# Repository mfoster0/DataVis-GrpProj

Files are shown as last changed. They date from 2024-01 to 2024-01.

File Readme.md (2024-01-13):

# Sea Ice Extent Gauge #
> CASA0019: Sensor Data Visualisation.

> Group 6 - Ice Ice Baby (Mark Foster, Satria Mitra Utama, Qingyao Tang).

<p align="center" width="100%">
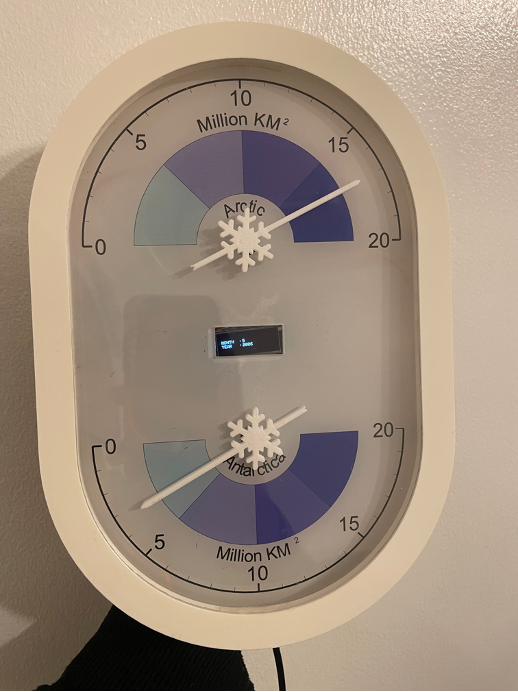
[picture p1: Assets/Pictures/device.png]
     
</p>

## Overview
This guide provides step-by-step instructions for building the Sea Ice Extent Gauge, a device designed to visualize changes in polar sea ice. This project, part of the CASA0019 course at University College London, aims to raise awareness about sea ice's importance and the impact of climate change.

## Table of Content
<details>
<summary>(click to expand)</summary>

1. Introduction
2. Components Required
3. Assembly Instructions
4. Software Setup
5. Using the Device
6. Additional Resources
7. References
8. Contributors

</details>

## 1. Introduction
The Sea Ice Extent Gauge visualizes real-time changes in Arctic and Antarctic sea ice coverage. It combines a physical device with an interactive digital twin, highlighting the urgency of environmental protection.

## 2. Components Required
- Raspberry Pico W microcontroller
- MG90S servos (2)
- 0.91-inch OLED display
- Metal Push Button LED
- Various electronic components (resistors, wires, etc.)

## 3. Assembly Instructions
### 3.1 Building the Hardware

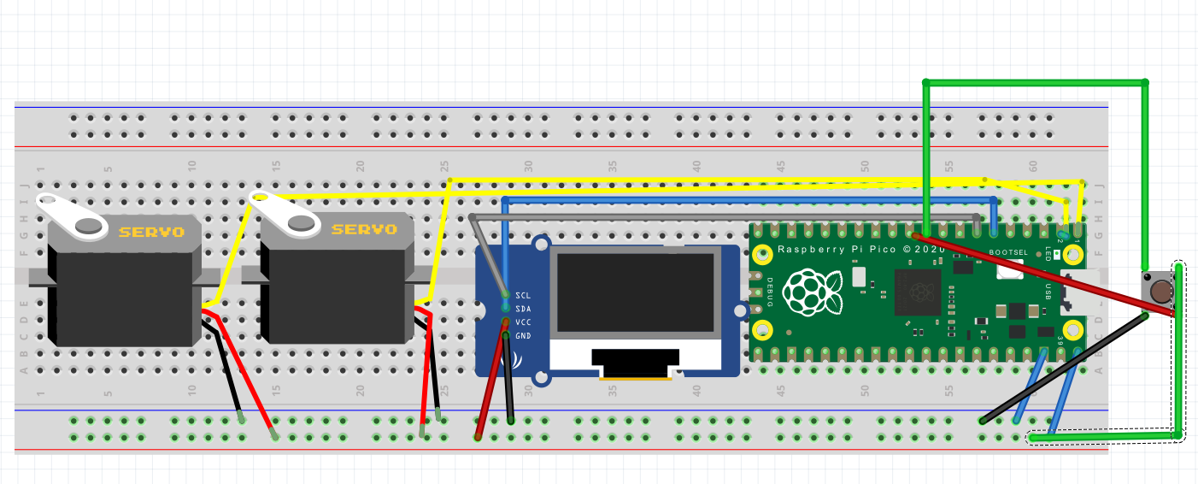
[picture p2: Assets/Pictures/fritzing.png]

Assemble the physical gauge using the Raspberry Pico W as the control center, connect the servos, OLED display, and LED push button according to the pin configuration provided.

|No|Components	    |Pin	|Raspberry Pico Pin|
---|----------------|:-----:|:----------------:|
|1 |Servo MG90S (1)	|VCC	|VBUS  | 
|  |	            |GND	|GND   |
|  |	            |Data	|GP0   |
|2 |Servo MG90S (2)	|VCC	|VBUS  |
|  |		        |GND	|GND   |
|  |	            |Data	|GP1   |
|3 |Oled Display 0.91 Inch|	VCC|	VBUS|
|	|	|GND|	GND|
|	|	|SDA	|GP4|
|	|	|SCL	|GP5|
|4|	LED Push Button|	VCC (+)	|GP8
|	|	|GND (-)	|GND
|	|	|SW0	|VBUS|
|	|	|SW1	|GP7|

### 3.2 Crafting the Physical Display
Create two semicircular charts to represent sea ice cover in the Arctic and Antarctic. Use shades of blue to indicate changes in ice coverage.

## 4. Software Setup
### 4.1 Programming the Raspberry Pico
#### 4.1.1 Install libraries
Set up the Raspberry Pico using Arduino IDE and run script `dial_gauge.ino`that collects data from MQTT Broker. 
Install necessary libraries like :
- [ESP8266 wifi](https://github.com/esp8266/Arduino/tree/master/libraries/ESP8266WiFi)
- [Pubsub client](https://www.arduino.cc/reference/en/libraries/pubsubclient/)
- [Adafruit Oled SSD1306](https://www.arduino.cc/reference/en/libraries/adafruit-ssd1306/)
- [Adafruit GFX Library](https://www.arduino.cc/reference/en/libraries/adafruit-gfx-library/)

#### 4.1.2 Config mqtt brokers & wifi
Create file named `arduino_secrets.h` within the same folder of the scripts and add your mqtt broker details 
```
//MQTT Broker & password
const char* mqttuser = "<username>";
const char* mqttpass = "<password>";
const char* mqtt_server = "<host>";
```
Don't forget to chane your wifi credentials on the scripts
```
const char* ssid = "<wifi>";
const char* password = "<password>";
```

### 4.2 Unity Augmented Reality Integration
Develop an AR version using Unity to mimic the physical device. Include additional functionalities like displaying videos and extra data on sea ice changes.

Scan this qrcode to install the AR application for Android

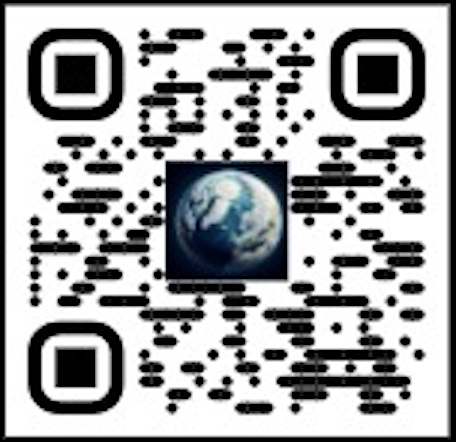
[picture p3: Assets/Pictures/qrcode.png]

## 5. Using the Device
### 5.1 Interacting with the Gauge
The device uses servos to indicate sea ice extent and an OLED display to show dates. Press the LED button to toggle between historical and current data.

### 5.2 Exploring the Digital Twin
Use the Unity AR interface to access more detailed information and visualizations about sea ice changes.

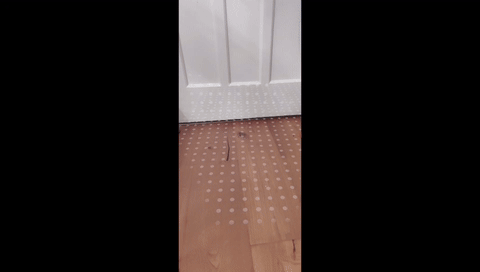
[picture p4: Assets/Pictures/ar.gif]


## 6. Additional Resources
- [GitHub Repository](https://github.com/mfoster0/DataVis-GrpProj)
- Assembly diagrams and schematics

## 7. Contributors
- Mark Foster
- Satria Mitra Utama
- Qingyao Tang

---

*This README was created for the Sea Ice Extent Gauge project, part of the CASA0019 course at University College London by Group 6, Ice Ice Baby.*

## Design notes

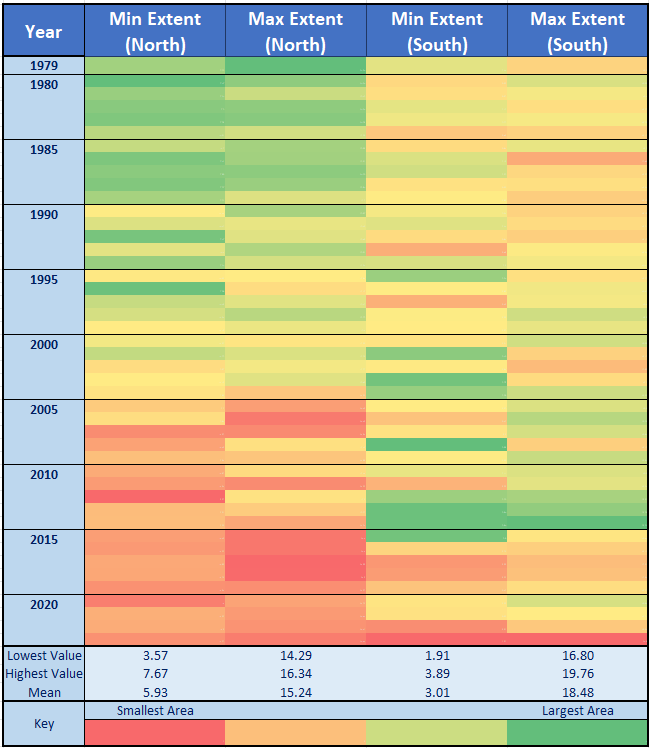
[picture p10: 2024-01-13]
Unity/Assets/Images/HeatMap.png

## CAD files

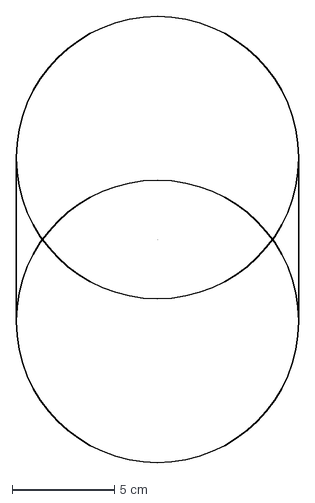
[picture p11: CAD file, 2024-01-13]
Assets/Acrylic/acrylic v1.dxf
13.8 x 21.8 cm

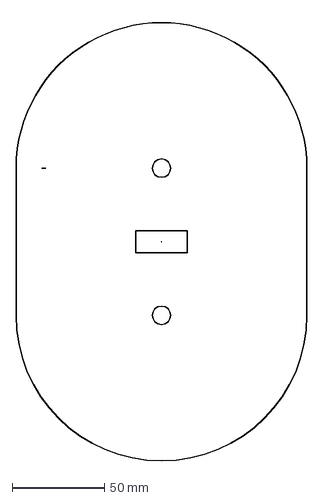
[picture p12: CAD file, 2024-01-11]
Assets/Face hole/face_platehole_1.dxf
158.0 x 241.5 mm

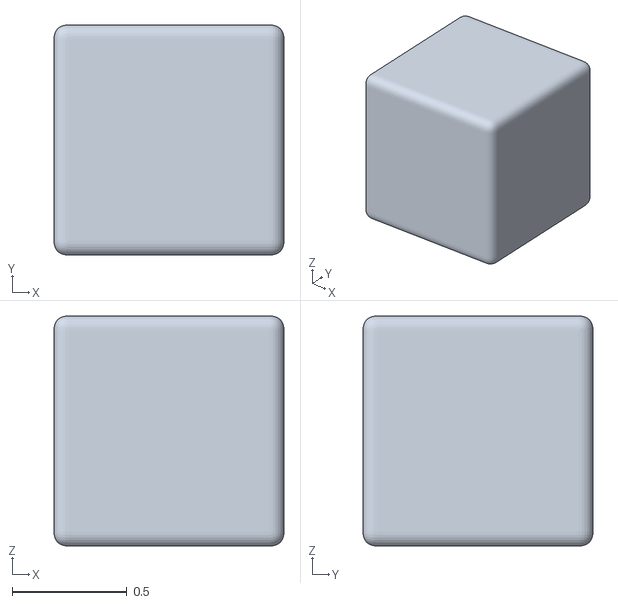
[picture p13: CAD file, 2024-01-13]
Unity/Assets/Plugins/CW/LeanCommon/Examples/Meshes/RoundedCube.obj
1.00 x 1.00 x 1.00

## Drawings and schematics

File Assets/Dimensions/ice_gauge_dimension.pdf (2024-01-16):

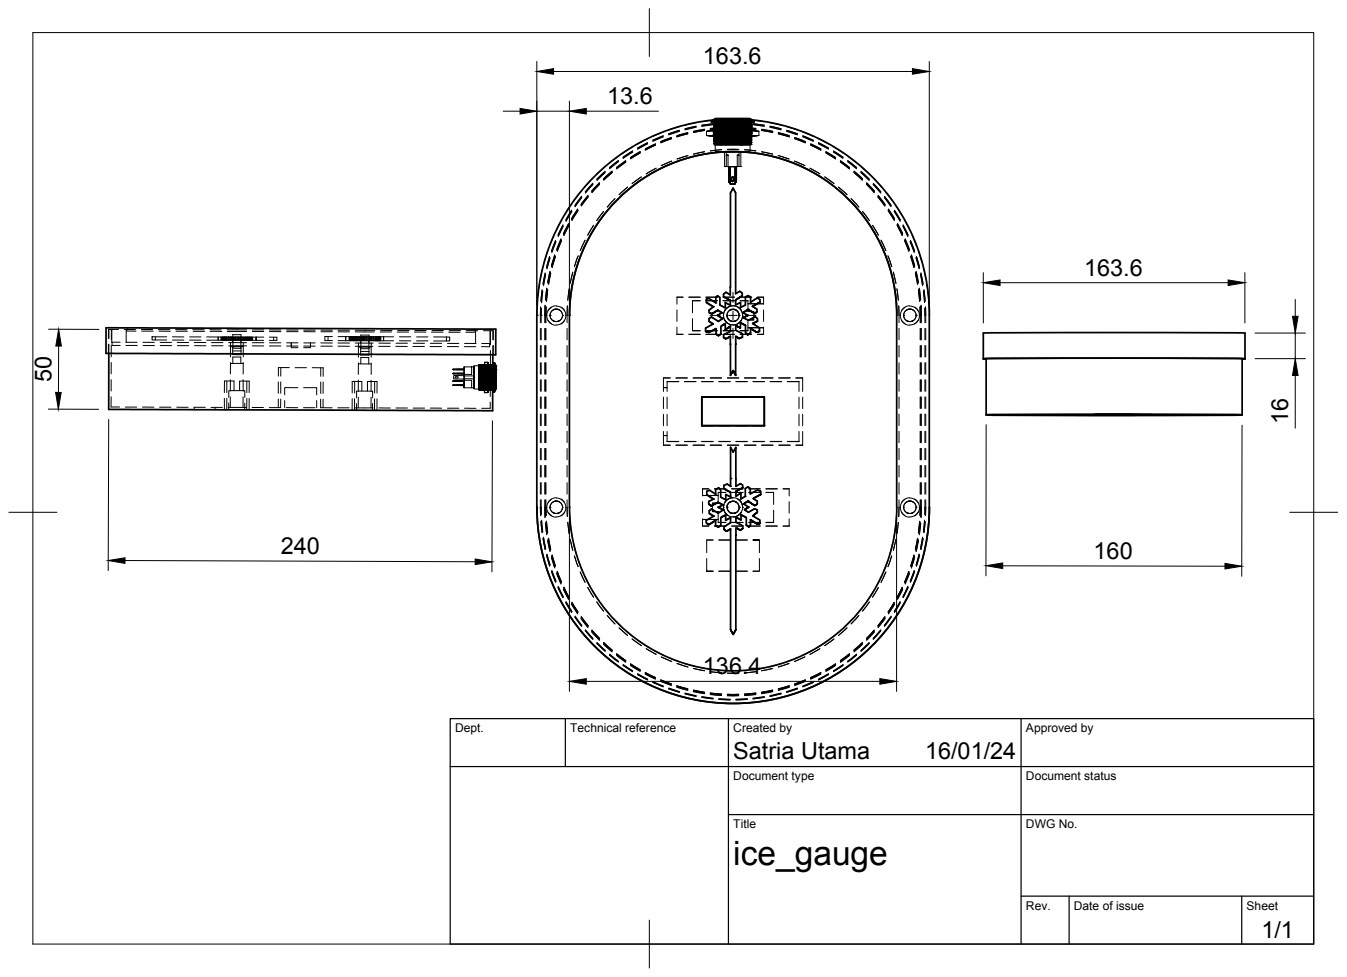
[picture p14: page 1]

Dept. | Technical reference | Created by Satria Utama 16/01/24 | Approved by

Document type | Document status

Title ice_gauge | DWG No.

Rev. | Date of issue | Sheet 1/1

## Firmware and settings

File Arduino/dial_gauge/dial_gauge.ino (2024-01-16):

#include <ESP8266WiFi.h>
#include <PubSubClient.h>
#include <Servo.h>
#include <Arduino.h>
#include <Adafruit_SSD1306.h>
#include <Adafruit_GFX.h>
#include <SPI.h>
#include <Wire.h>

#include "arduino_secrets.h"

char receivedMessage[5]; 
char monthReceived[5]; // Store the received month
char yearReceived[5];  // Store the received year
char stateReceived[5];  // Store the received year

// // Wifi at home
// const char* ssid = "VM9486848";
// const char* password = "5rfzxumhPkya8nxA";

// CE Lab wifi
const char* ssid = "CE-Hub-Student";
const char* password = "casa-ce-gagarin-public-service";

// // Wifi at Gintare
// const char* ssid = "4B87 Hyperoptic 1Gb Fibre 2.4Ghz";
// const char* password = "47EAgzx59EFA";

// Define topic to subscribe
const char* north = "student/CASA0019/G6/data/north";

const char* south = "student/CASA0019/G6/data/south";
const char* month = "student/CASA0019/G6/data/month";
const char* year = "student/CASA0019/G6/data/year";
const char* currentyear = "student/CASA0019/G6/data/currentyear";
const char* currentmonth = "student/CASA0019/G6/data/currentmonth";
const char* northDailyExtent = "student/CASA0019/G6/data/northDailyExtent";
const char* southDailyExtent = "student/CASA0019/G6/data/southDailyExtent";

const char* stateTopic = "student/CASA0019/G6/data/displayDaily";

int currentState = 0; // Variable to hold the current state

WiFiClient espClient;
PubSubClient client(espClient);

// Define servo objects
Servo servo1;
Servo servo2;

//Define LED Panel
Adafruit_SSD1306 display(128, 32);

//Define button pin
const int ledbutton = 8; // ESP8266's built-in LED pin
const int buttonPin = 7; // Define the pin for the button
int buttonState = 0; // Initialize variable to hold the button state
int lastButtonState = 0; // Initialize variable to hold the previous button state
int state = 0;

int ledState = 0; // Initialize variable to hold the LED state
//const int ledPin = LED_BUILTIN; // Define the pin for the LED

unsigned long lastDebounceTime = 0;  // the last time the output pin was toggled
unsigned long debounceDelay = 50;   

void setup() {
  Serial.begin(115200);
  delay(500);

  servo1.attach(2, 500, 2400); // Replace D1 with the pin number for servo 1
  servo2.attach(3, 500, 2400); // Replace D2 with the pin number for servo 2
  //servo1.write(3); 
  //servo2.write(3); 

  // // Servo Sweep - Useful for Calibration - Edit for own Servo/Dial Range
  // servo1.setEasingType(EASE_LINEAR);
  // servo2.setEasingType(EASE_LINEAR);

  // servo1.setSpeed(15);
  // servo2.setSpeed(15);

  Serial.print("Moving to 0");
  servo1.write(0);
  servo2.write(0);

  
  delay (1000);
  Serial.print("Moving to 180");
  servo1.write(180);
  servo2.write(180);

  delay (1000);
  
  Serial.print("Moving to 0");
  servo1.write(0);
  servo2.write(0);

  Serial.print("Pausing for 1 seconds");
  delay (2000);

  startWifi();

  client.setServer(mqtt_server, 1884);
  client.setCallback(callback);
  subscribeToTopic(north);
  subscribeToTopic(south);
  subscribeToTopic(month);
  subscribeToTopic(year);
  subscribeToTopic(northDailyExtent);
  subscribeToTopic(currentmonth);
  subscribeToTopic(currentyear);
  subscribeToTopic(southDailyExtent);

  subscribeToTopic(stateTopic);

  Serial.println("IP address: ");
  Serial.println(WiFi.localIP());




  display.begin(SSD1306_SWITCHCAPVCC, 0x3C);  // Address 0x3D for 128x32
  pinMode(buttonPin, INPUT); // Set the button pin as an input
  //pinMode(ledPin, OUTPUT); // Set LED pin as an output
  pinMode(ledbutton, OUTPUT); // Set LED pin as an output
  display.clearDisplay();

}

void loop() {
  client.loop();

  // Read the current state of the button
  int reading = digitalRead(buttonPin);

  // Check if the button state has changed
  if (reading != lastButtonState) {
    // Reset the debouncing timer
    lastDebounceTime = millis();
  }

  // If the button state has been different for longer than the debounce delay,
  // we assume that the button state has changed:
  if ((millis() - lastDebounceTime) > debounceDelay) {
    // If the button state has changed:
    if (reading != buttonState) {
      buttonState = reading;

      // Only toggle the state if the new button state is HIGH
      if (buttonState == HIGH) {
        Serial.println("Button Pressed");
        state = 1 - state;
        Serial.print("Current State: ");
        Serial.println(state);
        sendStateViaMQTT();
      }
    }
  }

  // Save the reading for the next loop
  lastButtonState = reading;
}

void sendStateViaMQTT() {
  char msg[10];
  snprintf(msg, 10, "%d", state);
  client.publish(stateTopic, msg);
}

// void checkState() {
//   if (currentState == 1) {
//     performTaskB(); // Perform Task B when the state is 1
//   } else {
//     performTaskA(); // Perform Task A when the state is 0
//   }
// }

void displayMessage(const char* month, const char* year) {
  display.clearDisplay();
  display.setTextColor(WHITE);
  // display.setTextSize(1);
  // display.setCursor(0, 0); // Set the cursor position
  // display.print(" Arctic: "); // Display the received message on the OLED
  // display.setCursor(62, 0); // Set the cursor position
  // display.print("Antarctica:"); // Display the received message on the OLED
  // display.setTextSize(2);
  // display.setCursor(0, 10); // Set the cursor position
  // display.print("15"); // Display the received message on the OLED
  // display.setCursor(27, 10); // Set the cursor position
  // display.print("KM"); // Display the received message on the OLED
  // display.setCursor(48, 10); // Set the cursor position
  // display.write(252);
  // display.setCursor(67, 10); // Set the cursor position
  // display.print("20"); // Display the received message on the OLED
  // display.setCursor(94, 10); // Set the cursor position
  // display.print("KM"); // Display the received message on the OLED
  // display.setCursor(115, 10); // Set the cursor position
  // display.write(252);

  display.setTextSize(1);
  display.setCursor(0, 10); // Set the cursor position
  display.print("MONTH  :"); // Display the received message on the OLED
  display.setCursor(50, 10); // Set the cursor position
  display.print(month); // Display the received message on the OLED
  display.setCursor(0, 20); // Set the cursor position
  display.print("YEAR   :"); // Display the received message on the OLED
  display.setCursor(50, 20); // Set the cursor position
  display.print(year); // Display the received message on the OLED

  display.display(); 
}


void reconnect() {
  while (!client.connected()) {
    Serial.print("Attempting MQTT connection...");
    String clientId = "ESP8266Client-";
    clientId += String(random(0xffff), HEX);

    if (client.connect(clientId.c_str(), mqttuser, mqttpass)) {
      Serial.println("connected");
      client.subscribe("student/CASA0019/G6/data/inTopic");
    } else {
      Serial.print("failed, rc=");
      Serial.print(client.state());
      Serial.println(" try again in 5 seconds");
      delay(5000);
    }
  }
}

void subscribeToTopic(const char* mqttTopic) {
  if (!client.connected()) {
    reconnect();
  }

  if (client.subscribe(mqttTopic)) {
    //Serial.print("Subscribed to topic: ");
    //Serial.println(mqttTopic);
  } else {
    //Serial.print("Failed to subscribe to topic: ");
    //Serial.println(mqttTopic);
  }
}

void startWifi() {
  Serial.println();
  Serial.print("Connecting to ");
  Serial.println(ssid);
  WiFi.begin(ssid, password);
  while (WiFi.status() != WL_CONNECTED) {
    delay(500);
    Serial.print(".");
  }
  Serial.println("");
  Serial.println("WiFi connected");
  Serial.print("IP address: ");
  Serial.println(WiFi.localIP());
}

void moveServo1(Servo& servo1, int value) {
  int invertedValue = 20 - value; // Invert the value from 0-20 to 20-0
  int angle = map(invertedValue, 0, 20, 0, 180);
  servo1.write(angle); // Move the servo to the mapped angle
   // Calculate the difference in angle
  //int angleDifference = abs(servo1.read() - angle);

  //if (angleDifference < 10) {
  //servo1.setSpeed(5); // Slower for small changes
  //servo1.setEasingType(EASE_LINEAR); // Linear easing for smoother small movements
  //} else {
  //servo1.setSpeed(10); // Faster for larger changes
  //servo1.setEasingType(EASE_CUBIC_IN_OUT); // Cubic easing for larger movements
  // }
  //   // Move servo to the new position
  // servo1.easeTo(angle);
  delay(10); // Allow transit time
}

void moveServo2(Servo& servo2, int value) {
  int angle = map(value, 0, 20, 0, 180); 
  servo2.write(angle); // Move the servo to the mapped angle
   // Calculate the difference in angle
  // int angleDifference = abs(servo2.read() - angle);

  // if (angleDifference < 10) {
  // //servo2.setSpeed(5); // Slower for small changes
  // //servo2.setEasingType(EASE_LINEAR); // Linear easing for smoother small movements
  // } else {
  // //servo2.setSpeed(10); // Faster for larger changes
  // //servo2.setEasingType(EASE_CUBIC_IN_OUT); // Cubic easing for larger movements
  // }
  //   // Move servo to the new position
  // servo2.easeTo(angle);
  delay(10); // Allow transit time
}

void callback(char* topic, byte* payload, unsigned int length) {
  Serial.print("Message arrived ");
  Serial.println(topic);
  
 // Ensure the payload is null-terminated
  char payloadStr[length + 1]; // Create a buffer with an extra space for the null terminator
  memcpy(payloadStr, payload, length); // Copy the payload to the buffer
  payloadStr[length] = '\0'; // Null-terminate the string

  // Convert the null-terminated payload to an integer
  int value = atoi(payloadStr);
  Serial.print("Received Value: ");
  Serial.println(value);

  if (strcmp(topic, stateTopic) == 0) {
    currentState = value; // Set the current state based on the received value
    Serial.print("Current State: ");
    Serial.println(currentState);

    // Control LED button based on currentState
    if (currentState != 0) {
      digitalWrite(ledbutton, HIGH); // Turn on LED button when currentState is 1
    } else {
      digitalWrite(ledbutton, LOW); // Turn off LED button when currentState is 0
    }
  } else {
    // Handle other topics without impacting LED button control
    if (currentState == 0) {
      if (strcmp(topic, north) == 0) {
        moveServo1(servo1, value); // Control servo 1 based on the received value from 'north'
      } else if (strcmp(topic, south) == 0) {
        moveServo2(servo2, value); // Control servo 2 based on the received value from 'south'
      } else if (strcmp(topic, month) == 0) {
        snprintf(monthReceived, sizeof(monthReceived), "%.*s", length, (char*)payload);
        displayMessage(monthReceived, yearReceived); // Display received month on OLED
      } else if (strcmp(topic, year) == 0) {
        snprintf(yearReceived, sizeof(yearReceived), "%.*s", length, (char*)payload);
        displayMessage(monthReceived, yearReceived); // Display received year on OLED
      }
    } else if (currentState == 1) {
      if (strcmp(topic, northDailyExtent) == 0) {
        moveServo1(servo1, value); // Control servo 1 based on the received value from 'northDailyExtent'
      } else if (strcmp(topic, southDailyExtent) == 0) {
        moveServo2(servo2, value); // Control servo 2 based on the received value from 'southDailyExtent'
      } else if (strcmp(topic, currentmonth) == 0) {
        snprintf(monthReceived, sizeof(monthReceived), "%.*s", length, (char*)payload);
        displayMessage(monthReceived, yearReceived); // Display received current month on OLED
      } else if (strcmp(topic, currentyear) == 0) {
        snprintf(yearReceived, sizeof(yearReceived), "%.*s", length, (char*)payload);
        displayMessage(monthReceived, yearReceived); // Display received current year on OLED
      }
    }
  }
  //value = 0;
}

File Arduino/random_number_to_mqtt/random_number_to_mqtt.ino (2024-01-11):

#include <ESP8266WiFi.h>
#include <PubSubClient.h>
#include <ArduinoJson.h>

//wifi CE lab
const char* ssid = "CE-Hub-Student";
const char* password = "casa-ce-gagarin-public-service";

//wifi home
// const char* ssid = "VM9486848";
// const char* password = "5rfzxumhPkya8nxA";

const char* mqtt_server = "mqtt.cetools.org";
const int mqtt_port = 1884;
const char* mqtt_user = "student";
const char* mqtt_password = "ce2021-mqtt-forget-whale";

WiFiClient espClient;
PubSubClient client(espClient);

void setup_wifi() {
  delay(10);
  Serial.println();
  Serial.print("Connecting to ");
  Serial.println(ssid);

  WiFi.begin(ssid, password);

  while (WiFi.status() != WL_CONNECTED) {
    delay(500);
    Serial.print(".");
  }

  Serial.println("");
  Serial.println("WiFi connected");
  Serial.println("IP address: ");
  Serial.println(WiFi.localIP());
}

void reconnect() {
  while (!client.connected()) {
    Serial.print("Attempting MQTT connection...");
    if (client.connect("ESP8266Client", mqtt_user, mqtt_password)) {
      Serial.println("connected");
    } else {
      Serial.print("failed, rc=");
      Serial.print(client.state());
      Serial.println(" try again in 5 seconds");
      delay(5000);
    }
  }
}

void setup() {
  Serial.begin(115200);
  setup_wifi();
  client.setServer(mqtt_server, mqtt_port);
}

void loop() {
  if (!client.connected()) {
    reconnect();
  }
  client.loop();

  int randomNumber1 = random(0, 181);
  int randomNumber2 = random(0, 181);
  const char* curmonth = "December";
  int curyear = 2023;


  // Publish JSON messages to separate topics
  char jsonString1[10];
  char jsonString2[10];
  char jsonString3[10];
  char jsonString4[10];
    char jsonString5[10];



  snprintf(jsonString1, sizeof(jsonString1), "%d", randomNumber1);
  snprintf(jsonString2, sizeof(jsonString2), "%d", randomNumber2);
  snprintf(jsonString3, sizeof(jsonString3), "%d", 15);
  snprintf(jsonString4, sizeof(jsonString4), "%s", curmonth);
  snprintf(jsonString5, sizeof(jsonString4), "%d", curyear);



  client.publish("student/CASA0016/ucfnmut/random1", jsonString1);
  client.publish("student/CASA0016/ucfnmut/random2", jsonString2);
  client.publish("student/CASA0016/ucfnmut/curData", jsonString3);
  client.publish("student/CASA0016/ucfnmut/curMonth", jsonString4);
  client.publish("student/CASA0016/ucfnmut/curyear", jsonString5);



  Serial.println(jsonString1);
  Serial.println(jsonString2);
  Serial.println(jsonString3);
  Serial.println(jsonString4);
  Serial.println(jsonString5);




  delay(10000);
}

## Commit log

2023-11-29 adding python data manipulation script
    [MonthlyData.csv]
2023-12-05 Upload the code for arduino
2024-01-11 update github
    [MonthlyData.csv, scale_fix v2.dxf, scale_platehole.dxf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]
2024-01-11 update assets folder
    [scale_fix v2.dxf, scale_platehole.dxf, scale_platehole_1.dxf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]
2024-01-11 update assets
    [face_platehole_1.dxf, scale_fix v2.dxf, scale_platehole.dxf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]
2024-01-12 Added .apk, Data folder, moved data files
    [MonthlyData.csv]
2024-01-12 Uploading Unity files
    Committing Unity files
    [RoundedCube.obj]
2024-01-12 Final check-in for data files
    Adding in python pull and publish scripts with the tester scripts
    [NorthDailyData.csv, SouthDailyData.csv]
2024-01-13 add assets
    [acrylic v1.dxf, ice gauge.fzz]
